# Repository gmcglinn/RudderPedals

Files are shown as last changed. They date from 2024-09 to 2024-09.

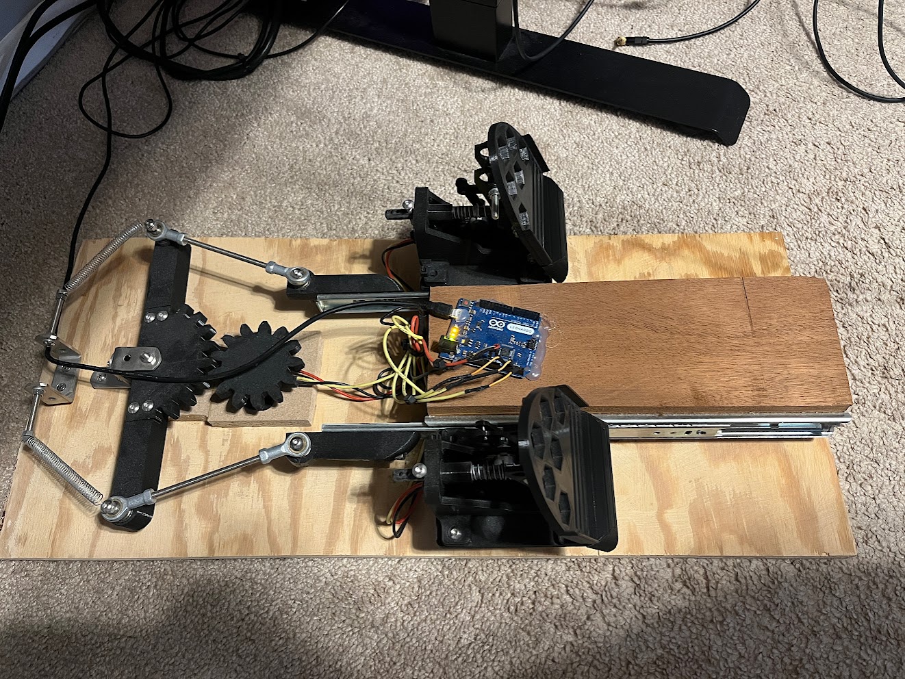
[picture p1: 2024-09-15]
Pictures/InPerson.jpg

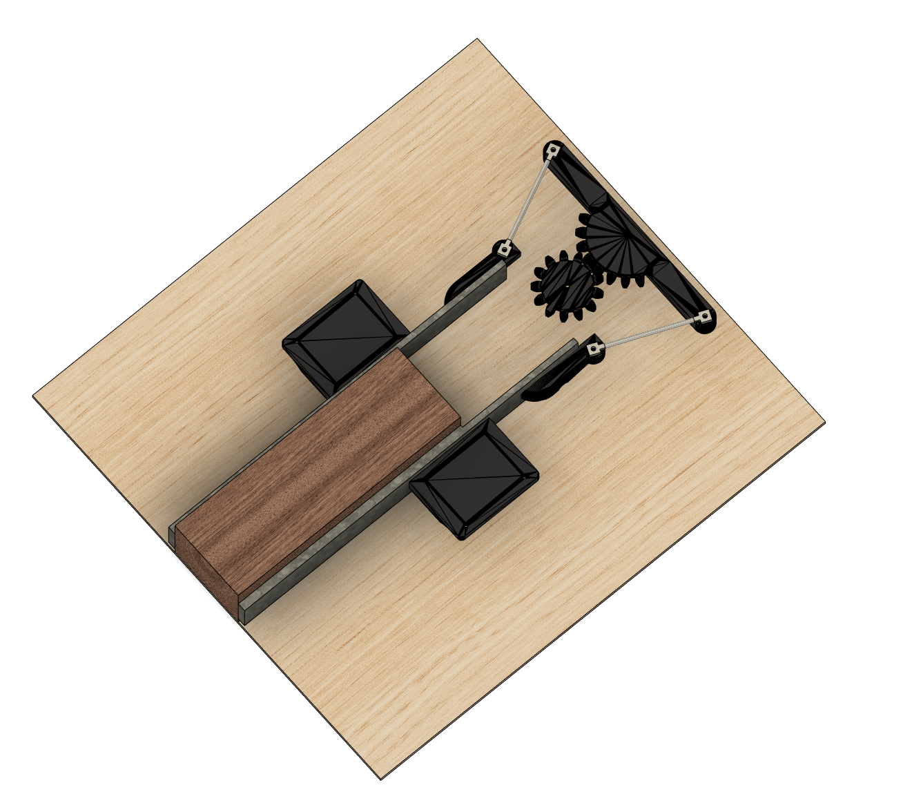
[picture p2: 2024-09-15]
Pictures/Screenshot (3).png

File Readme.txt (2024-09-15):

This is a thrown together solution for flight sim rudder pedals that I spent about a month on and off making in Fusion 360 and using the Joystick library for Arduino Leonardo. It's nowhere near as robust as an off the shelf purchased product from the likes of winwing and virpil, but I really wanted a linear pedal (not something that pivoted) and from my ~1 year of use so far it's been fine so long as I'm gentle with my inputs. It also came out to be cheaper than the budget plasticky off the shelf options.

The pedals themselves are originally from: https://www.thingiverse.com/thing:4550372 
I have significantly shortened the lever that connects to the pedals themselves. Additionally the heel plate and toe plate were made specifically for this application. I just hot glued/super glued the plates where I desired and they've held up alright. The spring kit I got off Amazon didn't sit well back to back so I made a simple washer/spacer that allows for two to be stacked back to back on the plunger to provide additional resistance. Original files relating to the pedals must be found at their creator's thingiverse link.

Please note that this is just a hobbyist project, and I can't make any guarantees following what I've done will get you results you are happy with yourself.

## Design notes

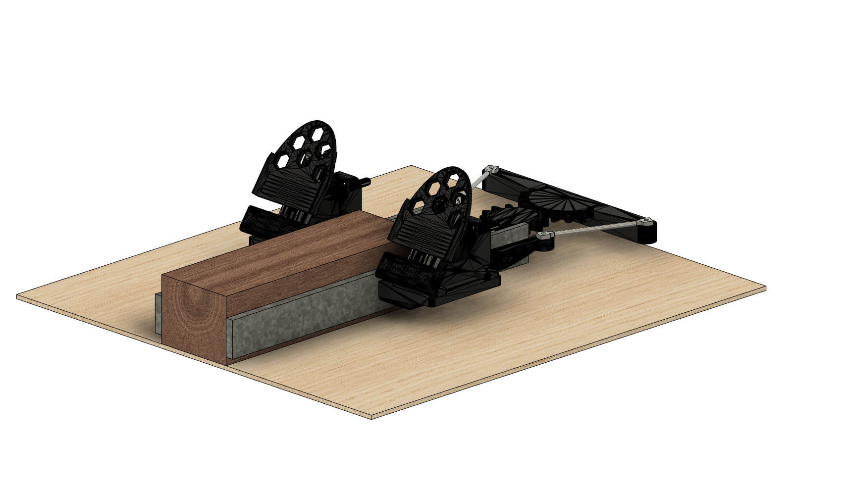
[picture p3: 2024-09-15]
Pictures/Screenshot (2).png

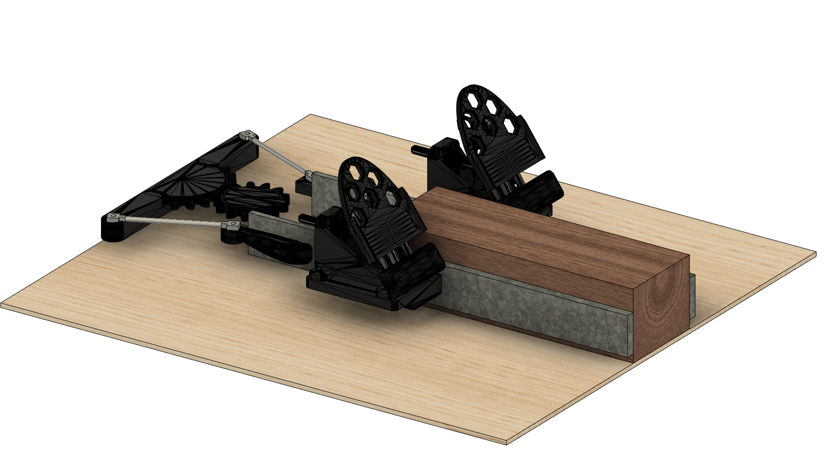
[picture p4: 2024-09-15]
Pictures/Screenshot (1).png

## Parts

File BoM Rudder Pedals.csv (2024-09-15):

Item Name | Link
Scrap 4x6 (30cm Long)
Scrap Plywood Board (28x65cm)
M5 Hardware | https://www.amazon.com/gp/product/B07CYHFQ7S/ref=ppx_yo_dt_b_asin_title_o09_s00?ie=UTF8&psc=1
M5 Threaded Rods (Cut to 10cm) | https://www.amazon.com/gp/product/B09FSZF1FR/ref=ppx_yo_dt_b_asin_title_o07_s00?ie=UTF8&th=1
Rose Joint | https://www.amazon.com/gp/product/B08P13KRLM/ref=ppx_yo_dt_b_asin_title_o08_s00?ie=UTF8&th=1
Misc Washers | https://www.amazon.com/gp/product/B009OK4TZO/ref=ppx_yo_dt_b_asin_title_o04_s00?ie=UTF8&psc=1
50mm M5 Bolts | https://www.amazon.com/gp/product/B09MRGZ473/ref=ppx_yo_dt_b_asin_title_o01_s00?ie=UTF8&th=1
10k Potentiometers | https://www.amazon.com/gp/product/B09XDR799P/ref=ppx_yo_dt_b_asin_title_o06_s00?ie=UTF8&th=1
Drawer Slides | https://www.amazon.com/gp/product/B0000DD4A1/ref=ppx_yo_dt_b_asin_title_o04_s00?ie=UTF8&th=1
Asst Springs | https://www.amazon.com/gp/product/B0B9BDRK25/ref=ppx_yo_dt_b_asin_title_o01_s00?ie=UTF8&psc=1
Ball Bearings | https://www.amazon.com/gp/product/B07ZNR134Z/ref=ppx_yo_dt_b_asin_title_o00_s00?ie=UTF8&psc=1
L Brackets | https://www.amazon.com/gp/product/B07N1KJBSW/ref=ppx_yo_dt_b_search_asin_title?ie=UTF8&psc=1

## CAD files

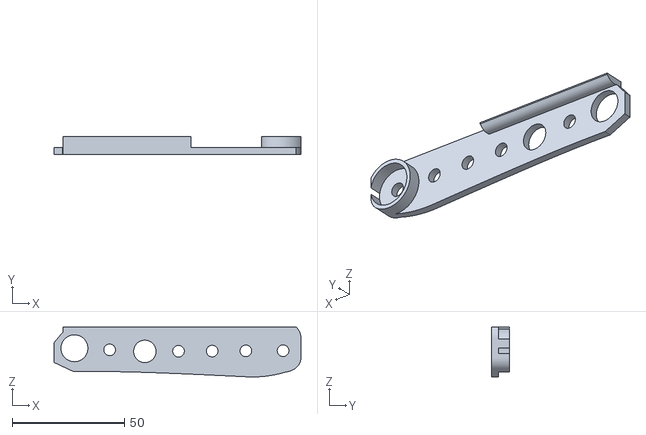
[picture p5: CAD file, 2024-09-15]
Modified Original Pedal Files/FlightPedalLeverR.stl
110.1 x 8.00 x 22.2

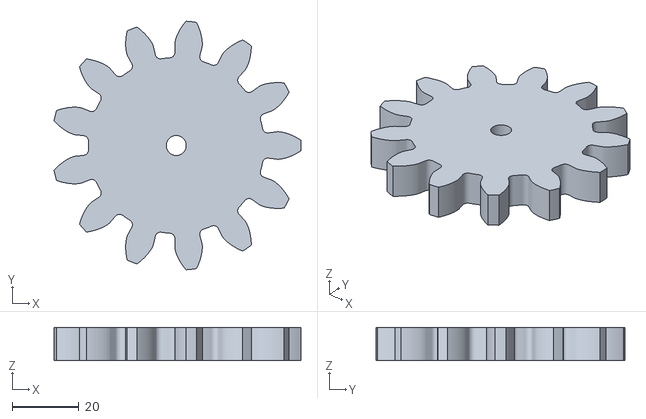
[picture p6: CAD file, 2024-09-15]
STL/PotPinion.stl
74.3 x 74.8 x 10.0

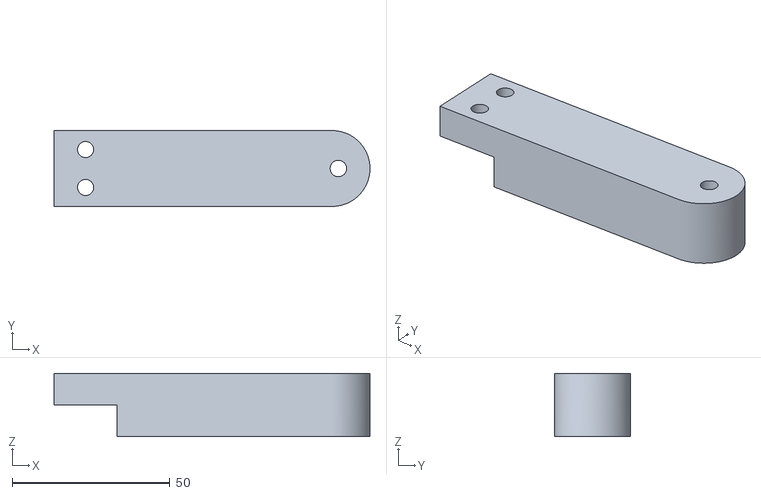
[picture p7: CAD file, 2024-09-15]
STL/BalanceArmOutter.stl
100.0 x 24.0 x 20.0

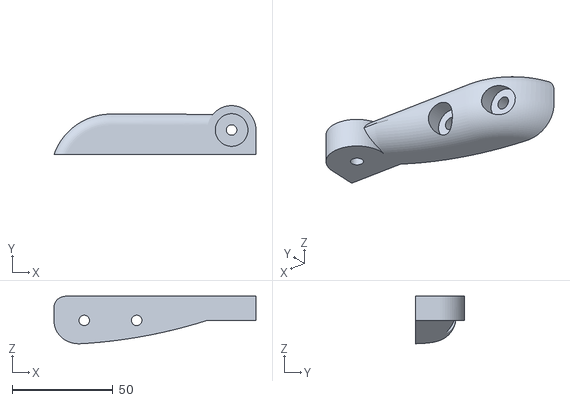
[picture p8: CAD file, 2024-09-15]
STL/RailToBalanceL.stl
100.2 x 24.2 x 23.6

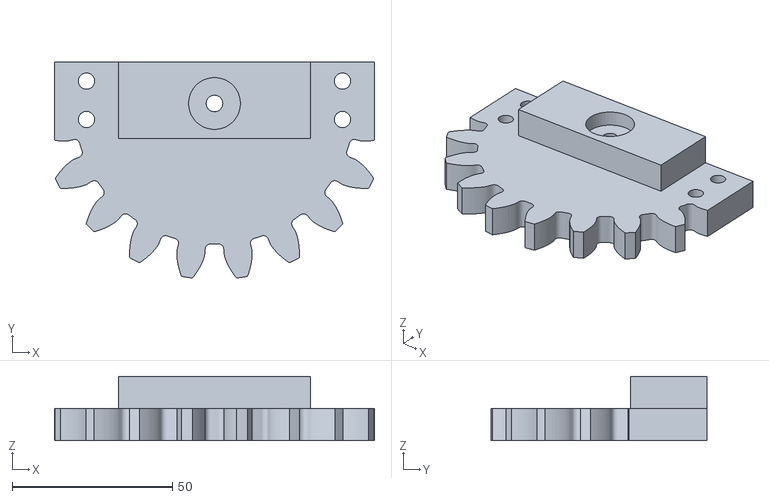
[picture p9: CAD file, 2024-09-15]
STL/BalanceGearMid.stl
100.0 x 67.6 x 20.0

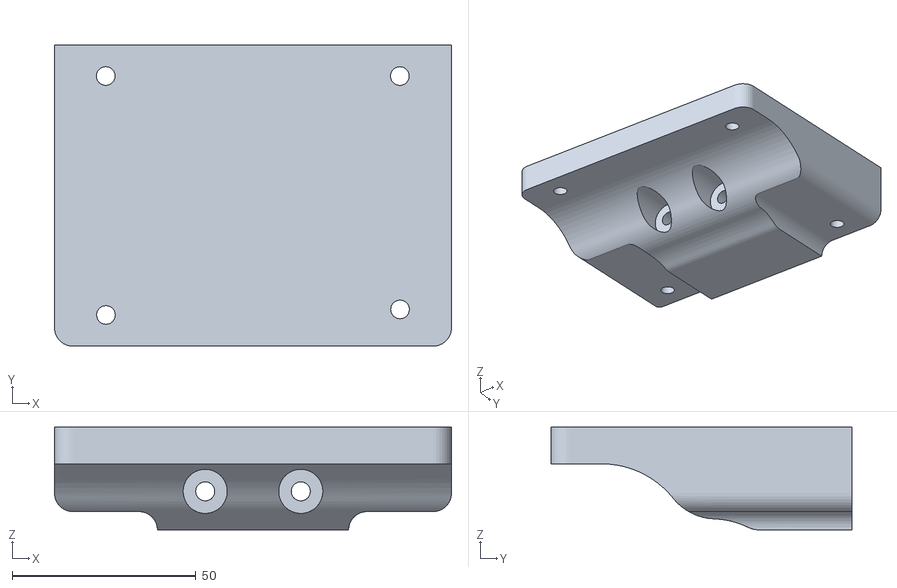
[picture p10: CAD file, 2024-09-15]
STL/PedalMountR.stl
108.0 x 82.0 x 28.0

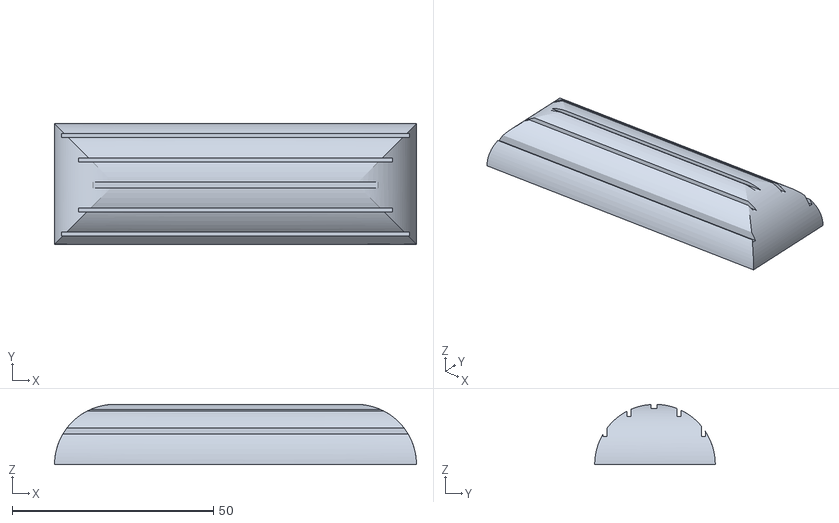
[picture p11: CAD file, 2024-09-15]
STL/HeelPlate.stl
90.0 x 30.0 x 15.0

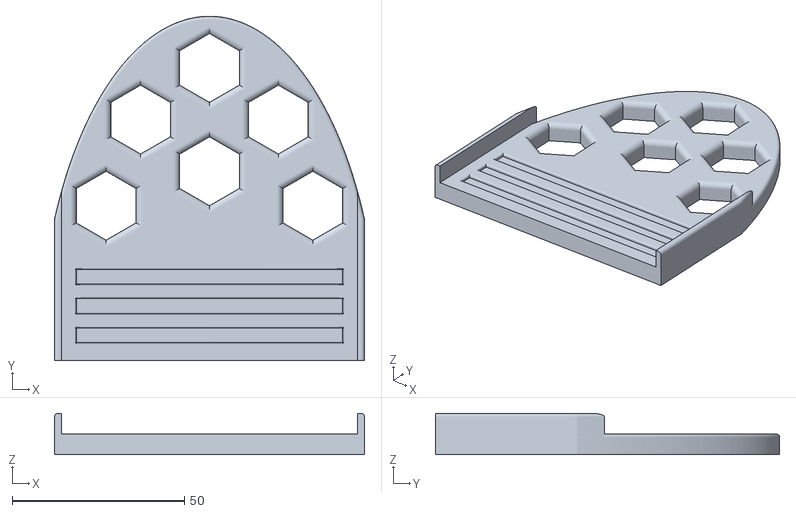
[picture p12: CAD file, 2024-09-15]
STL/ToePlate.stl
90.0 x 100.0 x 12.0

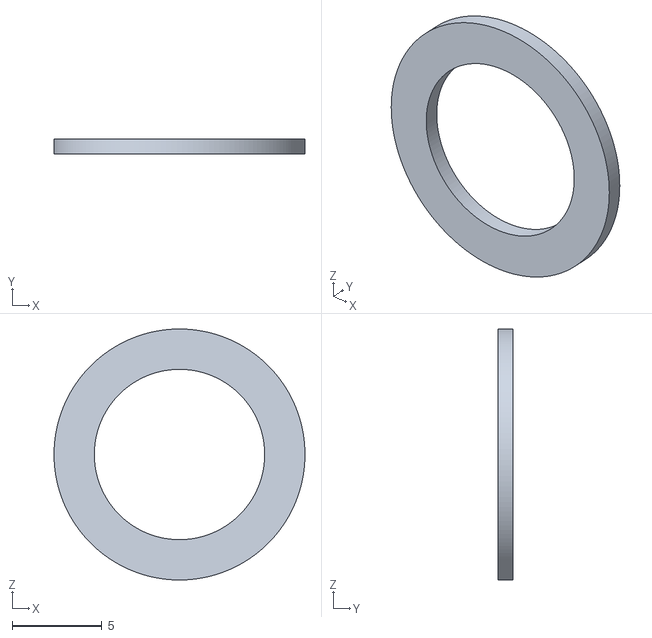
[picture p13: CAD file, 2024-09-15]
STL/SpringWasher.stl
14.0 x 0.863 x 14.0

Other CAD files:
Modified Original Pedal Files/FlightPedalLeverL.stl
STL/RailToBalanceR.stl
STL/PedalMountL.stl

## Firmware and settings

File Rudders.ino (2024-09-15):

#include <Joystick.h>

//Define Inputs
#define rudderPin A4
#define brakePinL A2
#define brakePinR A0 //Considered Accelerator

/*
Ranges
Rudder - 261 722
BrakeL - 389 503
BrakeR - 297 397
*/

//Joystick(HID ID, Joystick Type, Button Count, Hat Switch Count, Include X, Include Y, Include Z, Include Rx, Include Ry, Include Rz, Include Rudder, Include Throttle, Include Accelerator, Include Brake, Include Steering)

Joystick_ Joystick(0x15, JOYSTICK_TYPE_JOYSTICK, 0, 0, false, false, false, false, false, false, false, false, true, true, true);

const bool initAutoSendState = true;

//Default state for axis
int rudder_ = 0;
int brake_ = 0;
int accelerator_ = 0;

void setup() {

  /*
  pinMode(rudderZ, INPUT);
  pinMode(brakeL, INPUT);
  pinMode(brakeR, INPUT);
*/
  Joystick.begin();
 
}

void loop() {
  //Axis Runtime
  rudder_ = analogRead(rudderPin);
  rudder_ = map(rudder_, 261, 722, 0, 255);
  Joystick.setSteering(rudder_);
  Joystick.setSteeringRange(0,255);

  //Left Brake Pedal
  brake_ = analogRead(brakePinL);
  brake_ = map(brake_, 389, 503, 0, 255);
  Joystick.setBrake(brake_);
  Joystick.setBrakeRange(0,255);


  //Right Brake Pedal "Accelerator"
  accelerator_ = analogRead(brakePinR);
  accelerator_ = map(accelerator_, 297, 397, 0, 255);
  Joystick.setAccelerator(accelerator_);
  Joystick.setAcceleratorRange(0,255);

  //Pole Delay
  delay(10);
}

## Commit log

2024-09-15 Rudders main arduino file
2024-09-15 Rest of stuff
    [BalanceArmOutter.stl, BalanceGearMid.stl, FlightPedalLeverL.stl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]
2024-09-15 Adding bom
    really it's just the links to the stuff I bought
    [BoM Rudder Pedals.csv]
